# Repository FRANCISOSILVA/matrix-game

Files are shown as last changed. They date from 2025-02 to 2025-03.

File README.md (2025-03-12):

# Matrix-Game

Copyright (C) 2025 GWF AG, Obergrundstrasse 119, 6002 Lucerne, Switzerland

Contact: info@gwf.ch

## Trial Apprenticeship

This PCB is used as part of the trial apprenticeship for electronics/firmware at GWF AG in Lucerne.

_Deutsch: Schnupperlehre Elektroniker/in EFZ_

## Project

The project is used to practice soldering, measuring and potentially some coding.

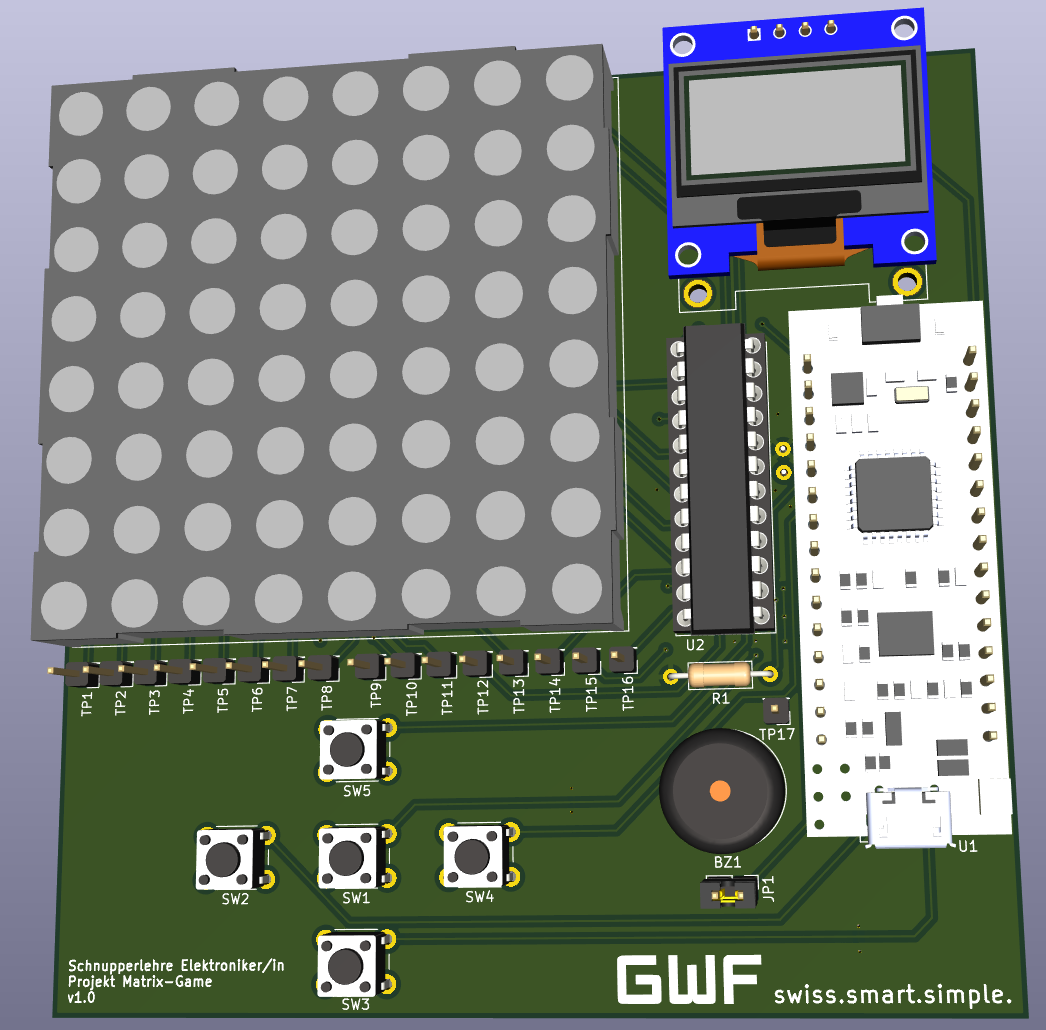
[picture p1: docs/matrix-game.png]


The firmware currently supports the following games:
- [x] Snake
- [x] Tic-Tac-Toe

Feel free to submit a Pull Request to add more games! :tada:

## Changelogs

The changelogs can be find in the corresponding subdirectories:
- [Firmware Changelog](firmware/CHANGELOG.md)
- [Hardware Changelog](hardware/CHANGELOG.md)

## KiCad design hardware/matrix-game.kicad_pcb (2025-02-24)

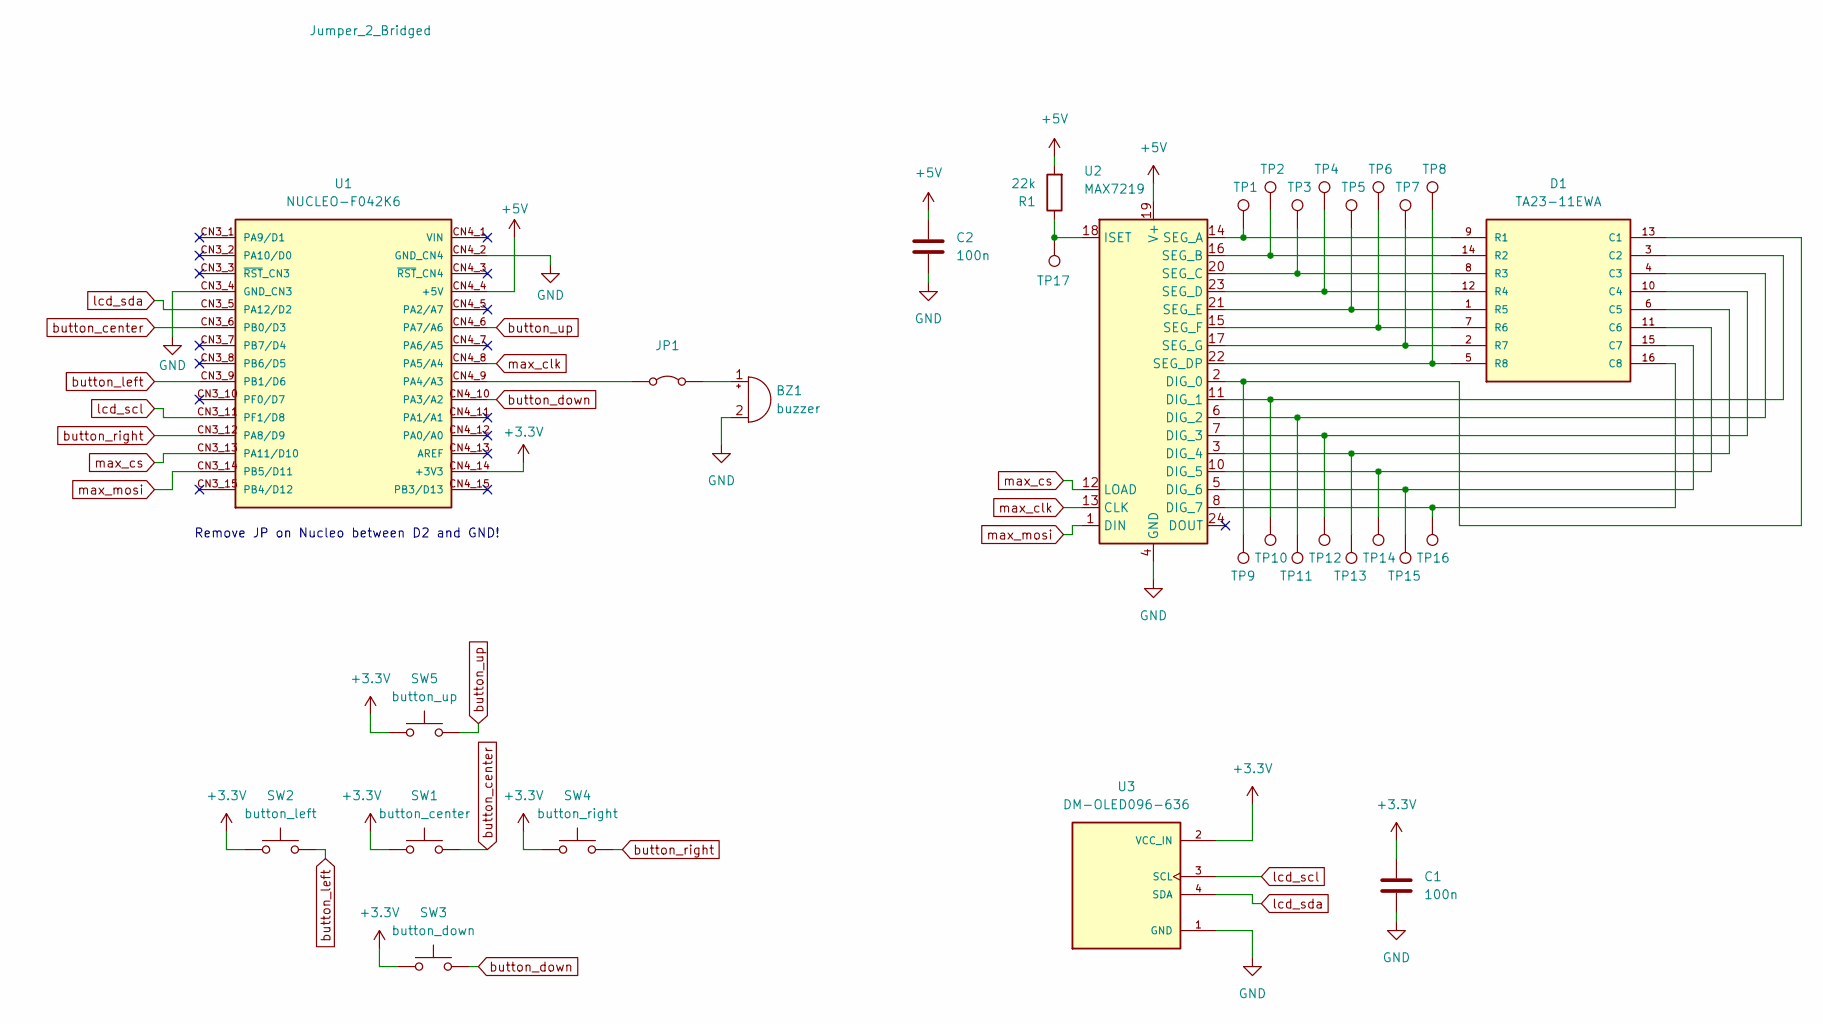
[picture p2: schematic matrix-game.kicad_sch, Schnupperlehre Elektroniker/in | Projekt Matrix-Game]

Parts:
BZ1: buzzer; Buzzer_12x9.5RM7.6
C1, C2: 100n; C_Disc_D3.0mm_W2.0mm_P2.50mm
D1: TA23-11EWA; LED_TA23-11EWA; PARTREV V.10A
JP1: Jumper_2_Bridged; PinHeader_1x02_P2.54mm_Vertical
R1: 22k; R_Axial_DIN0207_L6.3mm_D2.5mm_P10.16mm_Horizontal
SW1: button_center; SW_PUSH_6mm
SW2: button_left; SW_PUSH_6mm
SW3: button_down; SW_PUSH_6mm
SW4: button_right; SW_PUSH_6mm
SW5: button_up; SW_PUSH_6mm
TP1, TP2, TP3, TP4, TP5, TP6, TP7, TP8, TP9, TP10, TP11, TP12, TP13, TP14, TP15, TP16, TP17: TestPoint; PinHeader_1x01_P2.54mm_Vertical
U1: NUCLEO-F042K6; MODULE_NUCLEO-F042K6; PARTREV 8
U2: MAX7219; DIP-24_W7.62mm_Socket
U3: DM-OLED096-636; MODULE_DM-OLED096-636; PARTREV 2018-09-10

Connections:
+3.3V: C1.1, SW1.1, SW2.1, SW3.1, SW4.1, SW5.1, U1.CN4_14 (+3V3), U3.2 (VCC_IN)
+5V: C2.1, R1.2, U1.CN4_4 (+5V), U2.19 (V+)
GND: BZ1.2 (-), C1.2, C2.2, U1.CN3_4 (GND_CN3), U1.CN4_2 (GND_CN4), U2.4 (GND), U2.9 (GND), U3.1 (GND)
unnamed: BZ1.1 (+), JP1.2 (B)
unnamed: D1.13 (C1), TP9.1, U2.2 (DIG_0)
unnamed: D1.3 (C2), TP10.1, U2.11 (DIG_1)
unnamed: D1.4 (C3), TP11.1, U2.6 (DIG_2)
unnamed: D1.10 (C4), TP12.1, U2.7 (DIG_3)
unnamed: D1.6 (C5), TP13.1, U2.3 (DIG_4)
unnamed: D1.11 (C6), TP14.1, U2.10 (DIG_5)
unnamed: D1.15 (C7), TP15.1, U2.5 (DIG_6)
unnamed: D1.16 (C8), TP16.1, U2.8 (DIG_7)
unnamed: D1.9 (R1), TP1.1, U2.14 (SEG_A)
unnamed: D1.14 (R2), TP2.1, U2.16 (SEG_B)
unnamed: D1.8 (R3), TP3.1, U2.20 (SEG_C)
unnamed: D1.12 (R4), TP4.1, U2.23 (SEG_D)
unnamed: D1.1 (R5), TP5.1, U2.21 (SEG_E)
unnamed: D1.7 (R6), TP6.1, U2.15 (SEG_F)
unnamed: D1.2 (R7), TP7.1, U2.17 (SEG_G)
unnamed: D1.5 (R8), TP8.1, U2.22 (SEG_DP)
unnamed: JP1.1 (A), U1.CN4_9 (PA4/A3)
unnamed: R1.1, TP17.1, U2.18 (ISET)
button_center: SW1.2, U1.CN3_6 (PB0/D3)
button_down: SW3.2, U1.CN4_10 (PA3/A2)
button_left: SW2.2, U1.CN3_9 (PB1/D6)
button_right: SW4.2, U1.CN3_12 (PA8/D9)
button_up: SW5.2, U1.CN4_6 (PA7/A6)
lcd_scl: U1.CN3_11 (PF1/D8), U3.3 (SCL)
lcd_sda: U1.CN3_5 (PA12/D2), U3.4 (SDA)
max_clk: U1.CN4_8 (PA5/A4), U2.13 (CLK)
max_cs: U1.CN3_13 (PA11/D10), U2.12 (LOAD)
max_mosi: U1.CN3_14 (PB5/D11), U2.1 (DIN)

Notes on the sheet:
Remove JP on Nucleo between D2 and GND!

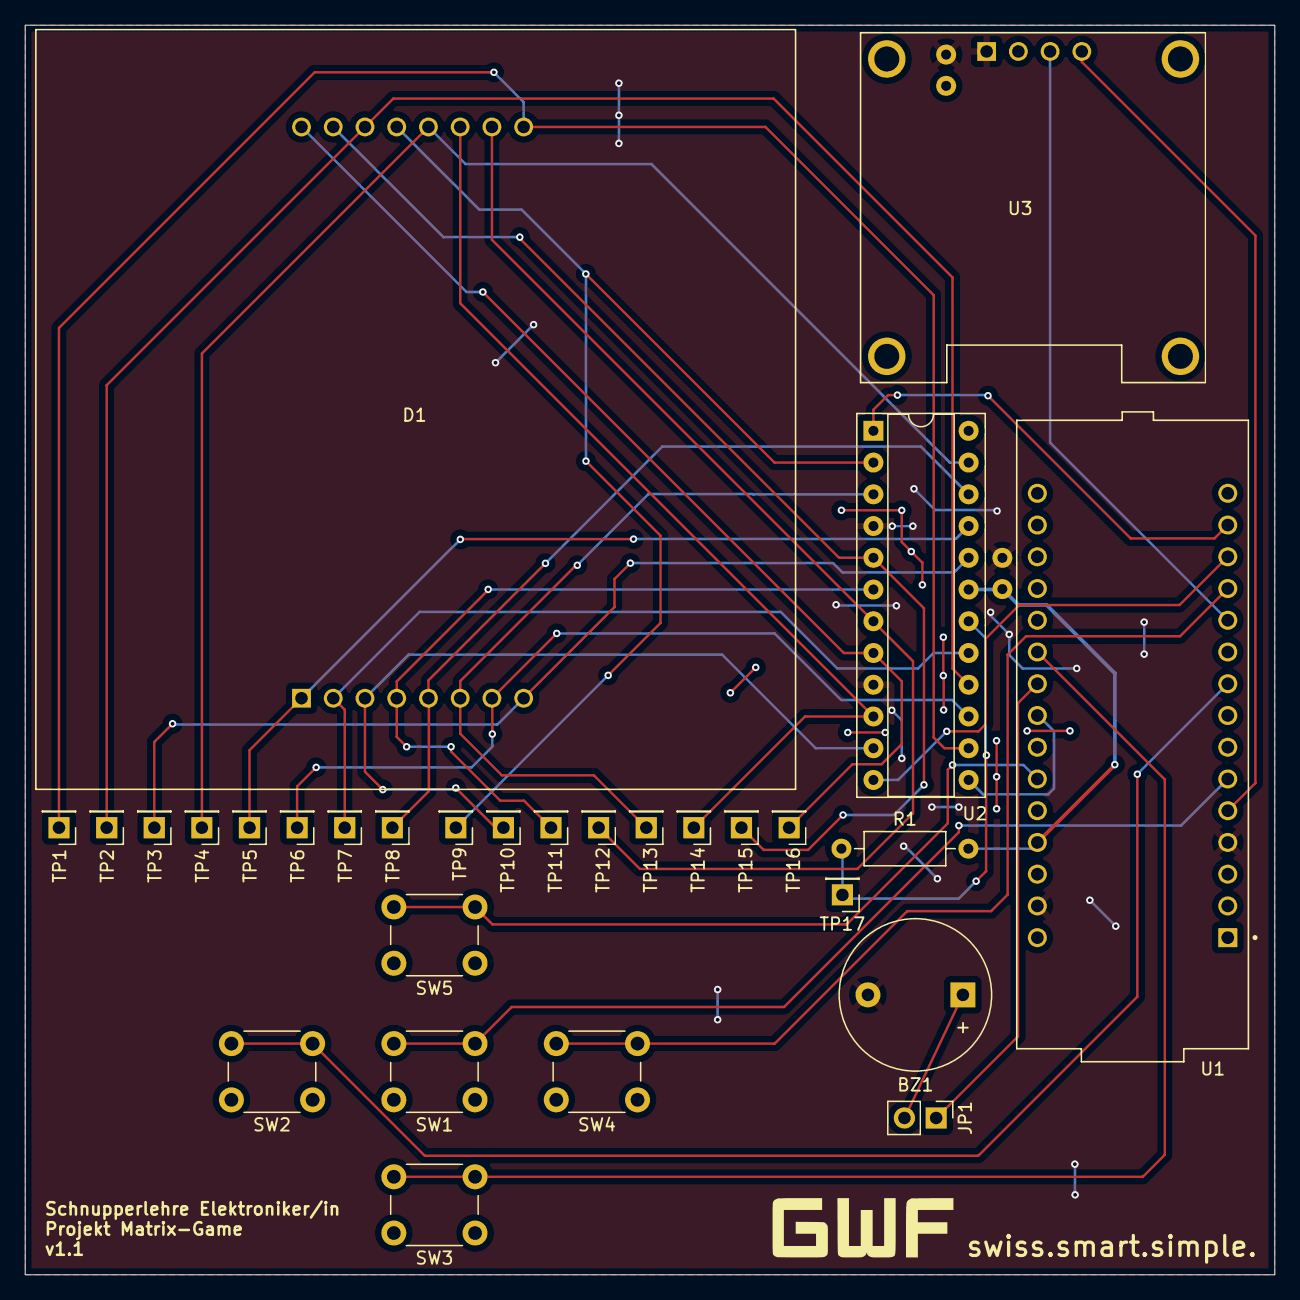
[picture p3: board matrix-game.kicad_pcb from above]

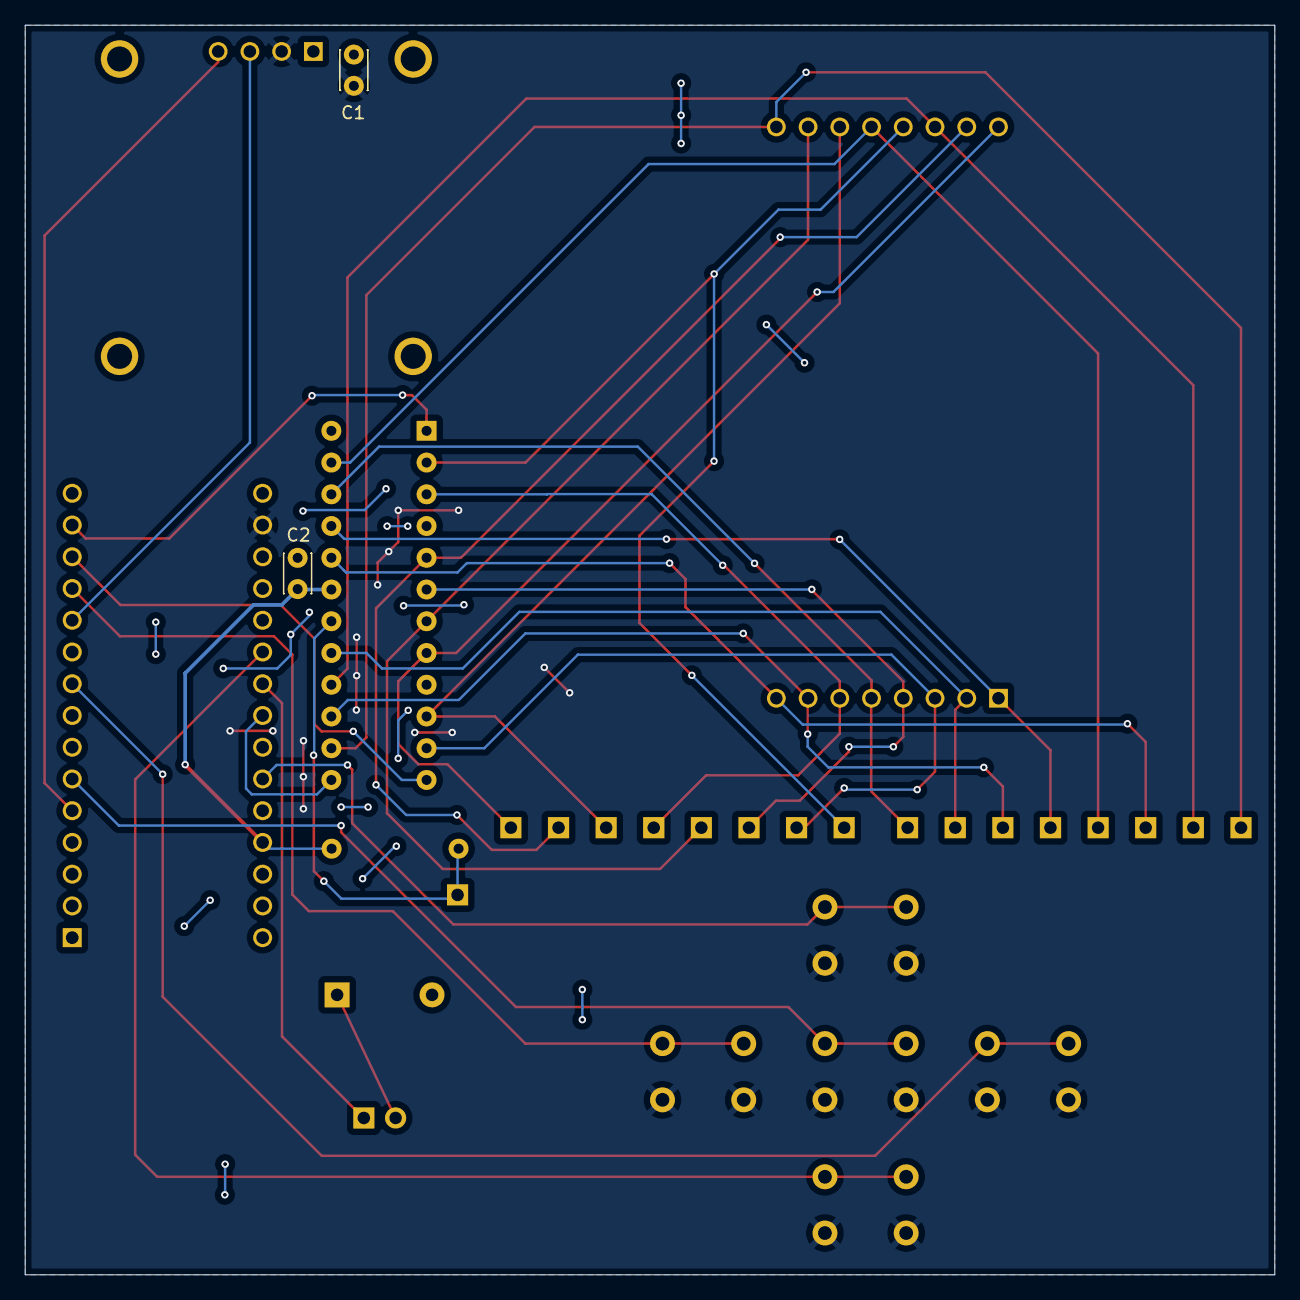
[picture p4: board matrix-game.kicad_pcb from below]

Board: 2 copper layers, 100.0 x 100.0 mm, 31 parts (2 on the bottom side), 32 nets.

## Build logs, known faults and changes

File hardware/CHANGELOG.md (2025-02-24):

# Matrix-Game Hardware Changelog

## [v1.1] -- 2025-02-24
============================

### Added:
    - [schematic] added text to remove JP on Nucleo between D2 and GND

### Fixed:
    - [schematic] changed value of R1: 10 kOhm --> 22 kOhm
    - [schematic] wrong connection of R1: GND --> +5V
    - [layout]    wrong connection of R1: GND --> +5V
    - [layout]    adjusted LCD footprint mounting hole distances: 22x22 mm --> 23.5x23.8 mm

## [v1.0] -- 2025-02-07
============================

Initial version

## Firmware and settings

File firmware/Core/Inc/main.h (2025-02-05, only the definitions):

#define MCO_Pin GPIO_PIN_0
#define MCO_GPIO_Port GPIOF
#define LCD_I2C_SCL_Pin GPIO_PIN_1
#define LCD_I2C_SCL_GPIO_Port GPIOF
#define VCP_TX_Pin GPIO_PIN_2
#define VCP_TX_GPIO_Port GPIOA
#define BUTTON_DOWN_Pin GPIO_PIN_3
#define BUTTON_DOWN_GPIO_Port GPIOA
#define BUZZER_Pin GPIO_PIN_4
#define BUZZER_GPIO_Port GPIOA
#define MAX_SPI_SCK_Pin GPIO_PIN_5
#define MAX_SPI_SCK_GPIO_Port GPIOA
#define BUTTON_UP_Pin GPIO_PIN_7
#define BUTTON_UP_GPIO_Port GPIOA
#define BUTTON_CENTER_Pin GPIO_PIN_0
#define BUTTON_CENTER_GPIO_Port GPIOB
#define BUTTON_LEFT_Pin GPIO_PIN_1
#define BUTTON_LEFT_GPIO_Port GPIOB
#define BUTTON_RIGHT_Pin GPIO_PIN_8
#define BUTTON_RIGHT_GPIO_Port GPIOA
#define MAX_SPI_CS_Pin GPIO_PIN_11
#define MAX_SPI_CS_GPIO_Port GPIOA
#define LCD_I2C_SDA_Pin GPIO_PIN_12
#define LCD_I2C_SDA_GPIO_Port GPIOA
#define SWDIO_Pin GPIO_PIN_13
#define SWDIO_GPIO_Port GPIOA
#define SWCLK_Pin GPIO_PIN_14
#define SWCLK_GPIO_Port GPIOA
#define VCP_RX_Pin GPIO_PIN_15
#define VCP_RX_GPIO_Port GPIOA
#define LED_GREEN_Pin GPIO_PIN_3
#define LED_GREEN_GPIO_Port GPIOB
#define MAX_SPI_MOSI_Pin GPIO_PIN_5
#define MAX_SPI_MOSI_GPIO_Port GPIOB

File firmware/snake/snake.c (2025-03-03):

/**
 * @file snake.c
 * @author Timon Burkard (timon.burkard@gwf.ch)
 *
 * @copyright Copyright (c) 2025 GWF AG
 *
 */

#include "snake.h"

#include <stdio.h>

#include "app.h"
#include "max7219.h"
#include "ssd1306.h"

#define NO_FOOD 0xFF

#define MAX_SNAKE_LENGTH 63

#define FLASH_HIGHSCORE_ADDRESS 0x08007F00 // Last page

#define SNAKE_SEQUENCE_PERIOD_10MS 25 // Period for each sequence (i.e., snake "steps") in multiple of 10ms

typedef enum {
    MOVE_NORMAL,    // A regular move (game not over; snake did not eat food)
    MOVE_EAT,       // Snake ate food
    MOVE_GAME_OVER, // Snake hit the wall or itself
} move_t;

typedef struct {
    uint8_t col;
    uint8_t row;
} coordinates_t;

typedef struct snake_part {
    uint8_t            col;
    uint8_t            row;
    struct snake_part* next;
} snake_part_t;

static snake_part_t* head                                                    = NULL;
static snake_part_t  snake_fields[MAX7219_COLUMN_AMOUNT][MAX7219_ROW_AMOUNT] = { 0 };

static snake_part_t food = { NO_FOOD, NO_FOOD };

static void     add_head(snake_part_t** snake_head, coordinates_t new_head);
static void     add_head_remove_tail(snake_part_t** snake_head, coordinates_t new_head);
static bool     is_game_over(coordinates_t new_head);
static bool     is_eating(coordinates_t new_head);
static move_t   apply_new_head(snake_part_t** snake_head, coordinates_t new_head);
static move_t   move_left(snake_part_t** snake_head);
static move_t   move_right(snake_part_t** snake_head);
static move_t   move_up(snake_part_t** snake_head);
static move_t   move_down(snake_part_t** snake_head);
static uint8_t  calc_score(void);
static void     print_score(uint16_t score);
static void     flash_init_highscore(void);
static uint16_t flash_load_highscore(void);
static void     flash_save_highscore(uint16_t score);
static void     convert_to_matrix(bool matrix[MAX7219_COLUMN_AMOUNT][MAX7219_ROW_AMOUNT]);
static void     init(void);
static void     lcd_start(void);
static void     food_generate(void);
static void     handle_score(void);
static move_t   move_snake(button_t direction);
static void     start_game(button_t* direction);

void snake(void)
{
    button_t button     = BUTTON_NONE;
    button_t direction  = BUTTON_RIGHT;
    move_t   move_state = MOVE_NORMAL;

    srand(HAL_GetTick());

    flash_init_highscore();

    init();
    lcd_start();
    start_game(&direction);

    while (app_get_user_input() == BUTTON_NONE) {
        // Wait for user to start the game
    }

    do {
        app_beep(BEEP_SHORT_MS);
        food_generate();

        do {
            for (uint8_t i = 0; i < SNAKE_SEQUENCE_PERIOD_10MS; i++) {
                button = app_get_user_input(); // Takes 10 ms

                if ((button != BUTTON_NONE) && (button != BUTTON_CENTER)) {
                    direction = button;
                }
            }

            move_state = move_snake(direction);

            convert_to_matrix(matrix);

            if (max7219_set_matrix(&max7219, matrix) != MAX7219_OK) {
                for (;;) {
                } // Error handling...
            }
        } while (move_state == MOVE_NORMAL);
    } while (move_state != MOVE_GAME_OVER);

    app_beep(BEEP_LONG_MS);
    handle_score();

    while (app_get_user_input() == BUTTON_NONE) {
        // Wait for user to start the game
    }
}

static void init(void)
{
    for (uint8_t i = 0; i < MAX7219_COLUMN_AMOUNT; i++) {
        for (uint8_t j = 0; j < MAX7219_ROW_AMOUNT; j++) {
            snake_fields[i][j].col  = i;
            snake_fields[i][j].row  = j;
            snake_fields[i][j].next = NULL;
        }
    }
}

static void lcd_start(void)
{
    char highscore[20] = "";

    sprintf(highscore, "Highscore: %d", flash_load_highscore());

    app_lcd_print_title();

    SSD1306_GotoXY(0, APP_LCD_ROW_GAME_NAME);
    SSD1306_Puts("Snake Game", &Font_7x10, 1);
    SSD1306_GotoXY(0, APP_LCD_ROW_GAME_DYNAMIC_0);
    SSD1306_Puts(highscore, &Font_7x10, 1);
    SSD1306_UpdateScreen();
}

static void convert_to_matrix(bool matrix[MAX7219_COLUMN_AMOUNT][MAX7219_ROW_AMOUNT])
{
    snake_part_t* temp = head;

    app_matrix_clean(matrix);

    while (temp != NULL) {
        matrix[temp->col][temp->row] = true;
        temp                         = temp->next;
    }

    if (food.col != NO_FOOD) {
        matrix[food.col][food.row] = true;
    }
}

static void food_generate(void)
{
    do {
        food.col = rand() % MAX7219_COLUMN_AMOUNT;
        food.row = rand() % MAX7219_ROW_AMOUNT;
    } while (matrix[food.col][food.row] == true);
}

/**
 * @brief Snake move
 *
 * @param direction
 *
 * @return move_t
 */
static move_t move_snake(button_t direction)
{
    switch (direction) {
    case BUTTON_UP:
        return move_up(&head);

    case BUTTON_DOWN:
        return move_down(&head);

    case BUTTON_LEFT:
        return move_left(&head);

    case BUTTON_RIGHT:
        return move_right(&head);

    default:
        return MOVE_GAME_OVER; // Not reachable
    }
}

static void handle_score(void)
{
    uint16_t score = calc_score();
    print_score(score);

    uint16_t highscore = flash_load_highscore();

    if (score > highscore) {
        flash_save_highscore(score);
    }
}

static void start_game(button_t* direction)
{
    // Start at the middle
    head       = &snake_fields[MAX7219_COLUMN_AMOUNT / 2][MAX7219_ROW_AMOUNT / 2];
    head->next = NULL;

    food.col = NO_FOOD;
    food.row = NO_FOOD;

    convert_to_matrix(matrix);

    if (max7219_set_matrix(&max7219, matrix) != MAX7219_OK) {
        for (;;) {
        } // Error handling...
    }

    *direction = BUTTON_RIGHT;
}

static void add_head(snake_part_t** snake_head, coordinates_t new_head)
{
    snake_part_t* new_head_node = &snake_fields[new_head.col][new_head.row];

    new_head_node->next = *snake_head;

    *snake_head = new_head_node;
}

static void add_head_remove_tail(snake_part_t** snake_head, coordinates_t new_head)
{
    snake_part_t* temp;
    snake_part_t* new_head_node = &snake_fields[new_head.col][new_head.row];

    new_head_node->next = *snake_head;

    if ((*snake_head)->next == NULL) {
        // The snake had only one part
        new_head_node->next = NULL;
        *snake_head         = new_head_node;
        return;
    }

    temp = *snake_head;

    while (temp->next->next != NULL) {
        temp = temp->next;
    }

    // Remove last part
    temp->next = NULL;

    *snake_head = new_head_node;
}
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

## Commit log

2025-02-05 [project/firmware] initial config for LCD I2C
2025-02-05 [project/firmware/lcd] added driver for LCD
    Source: https://controllerstech.com/oled-display-using-i2c-stm32/
2025-02-05 [project/firmware/lcd] added example how to use LCD driver
2025-02-05 [project/firmware/max] initial config for MAX7219 SPI
2025-02-05 [project/firmware/led] added user led LD3
    Not to forget that this GPIO is connected to the green Nucleo user led LD3.
2025-02-05 [project/firmware/buttons] added buttons
2025-02-07 [project/hardware] initial commit of empty KiCad project
    [matrix-game.kicad_pcb, matrix-game.kicad_sch]
2025-02-07 [project/hardware/schematic] added nucleo board and buttons
    [matrix-game.kicad_sch]
2025-02-07 [project/hardware/schematic] added max7219 and led matrix
    [matrix-game.kicad_sch]
2025-02-07 [project/hardware/schematic] added LCD
    [matrix-game.kicad_sch]
2025-02-07 [project/hardware/schematic] added custom symbol for LCD, assigned footprints
    [matrix-game.kicad_pcb, matrix-game.kicad_sch]
2025-02-07 [project/hardware/layout] added custom footprint for LCD
    [matrix-game.kicad_pcb, matrix-game.kicad_sch]
2025-02-07 [project/hardware/layout] started layouting
    [matrix-game.kicad_pcb]
2025-02-07 [project/hardware/layout] set all tracks to 0.2 mm width
    [matrix-game.kicad_pcb]
2025-02-07 [project/hardware/layout] rotation of matrix LED
    [matrix-game.kicad_pcb]
2025-02-07 [project/hardware] added test points
    [matrix-game.kicad_pcb, matrix-game.kicad_sch]
2025-02-07 [project/hardware] added jumper for buzzer
    [matrix-game.kicad_pcb, matrix-game.kicad_sch]
2025-02-07 [project/hardware] added capacitors for LCD and MAX7219, logo and version
    [matrix-game.kicad_pcb, matrix-game.kicad_sch]
2025-02-07 [project/hardware] added page settings
    [matrix-game.kicad_sch]
2025-02-07 [project/hardware/layout] more layouting
    [matrix-game.kicad_pcb, matrix-game.kicad_sch]
2025-02-07 [project/hardware/layout] make 5V trace a bit thicker
    [matrix-game.kicad_pcb]
2025-02-07 [project/hardware/schematic] added labels
    [matrix-game.kicad_pcb, matrix-game.kicad_sch]
2025-02-07 [project/hardware/layout] turned TP labels to be better readable
    [matrix-game.kicad_pcb]
2025-02-07 [project/hardware/layout] gerber settings
    [matrix-game.kicad_pcb]
2025-02-07 [project/hardware/3d] added STEP for Nucleo and matrix LED
    [matrix-game.kicad_pcb]
2025-02-07 [project/hardware] added library model for LCD, added sockets for Nucleo and LCD
    [matrix-game.kicad_pcb, matrix-game.kicad_sch]
2025-02-07 [project/hardware/3d] added 3D models for MA7219 and jumper
    [matrix-game.kicad_pcb]
2025-02-10 [project/hardware/schematic/minor] remove duplicated connection
    [matrix-game.kicad_sch]
2025-02-10 [project/hardware/layout] added page setup
    [matrix-game.kicad_pcb]
2025-02-17 [project/firmware/gpio] default pin state for CS should be High
2025-02-17 [project/firmware/max] added driver for MAX7219
    This is the multiplexer / LED driver for the LED matrix.
2025-02-17 [project/firmware] added examples for max7219 driver usage
2025-02-17 [project/firmware] refactoring: max7219_init() should also apply default configuration
    And also added a dedicated function to clear the matrix LED.
2025-02-18 [project/firmware/minor] rename lcd folder
    Lets follow the convention to have user directories in lower case.
2025-02-18 [project/firmware] fix: do not abort game if CENTER button is pressed
    Previously the game was terminated by `snake_move()` when CENTER button
    was pressed.
    Now, the CENTER button is simply ignored while playing the snake game.
    [app.c]
2025-02-24 [project/hardware] changed value of R1
    [matrix-game.kicad_sch]
2025-02-24 [project/hardware] fix: wrong connection of R1
    R1 was wrongly connectet to GND instead of +5V
    [matrix-game.kicad_pcb, matrix-game.kicad_sch]
2025-02-24 [project/hardware] added text: Remove JP on Nucleo between D2 and GND!
    [matrix-game.kicad_sch]
2025-02-24 [project/hardware] fix: footprint of LCD
    Adjusted mouting hole distances:
    - previous[mm]: 22x22
    - now[mm]: 23.5x23.8
    [matrix-game.kicad_pcb]
2025-02-24 [project/hardware] v1.1
    [matrix-game.kicad_pcb, matrix-game.kicad_sch]
2025-03-10 [general] move project structure one level up
    Initially, the idea was to have multiple things about the trial
    apprenticeship in this repo, the matrix-game project being one of them.
    Now, we use this repo only for the matrix-game, so lets move the files
    one level up.
    [matrix-game.kicad_pcb, matrix-game.kicad_sch]

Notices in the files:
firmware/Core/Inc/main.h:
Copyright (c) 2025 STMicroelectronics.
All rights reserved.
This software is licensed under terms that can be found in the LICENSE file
